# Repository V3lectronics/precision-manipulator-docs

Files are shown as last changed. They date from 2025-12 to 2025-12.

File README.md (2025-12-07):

# Precision Manipulator Docs
This is a university project about designing a precision XY manipulator that works only by mechanical means (no electricity). I have calculated the construction and designed this by myself using Autodesk Inventor.

# Images



rys-msl



# Use cases
- microscope tables
- assembly of small devices/systems e.g. robots
- any application requiring precise linear motion in 1 or 2 axis

# Technical drawings
.dwg and .pdf files can be downloaded from this repository.

# License
CERN Open Hardware Licence Version 2 - Strongly Reciprocal

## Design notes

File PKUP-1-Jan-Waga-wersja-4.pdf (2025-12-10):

P O L I T E C H N I K A W A R S Z A W S K A

PODSTAWY KONSTRUKCJI URZĄDZEŃ PRECYZYJNYCH

# Projekt 1

Temat nr MSL-25

# Moduł stolika liniowego

# Założenia konstrukcyjne

Wykonał: Jan Waga gr. MT-132 (B) Prowadzący: dr inż. Zbigniew Kusznierewicz

Warszawa 2025/2026

# Spis treści

Założenia konstrukcyjne | 1
Spis treści | 2
1. Wprowadzenie | 3
2. Wymagania techniczne | 3
3. Obliczenia konstrukcyjne | 4
Maksymalna długość separatora i prowadnic | 4
Liczba oraz średnica kulek | 4
Rzeczywista długość separatora | 5
Analiza obciążeń elementów tocznych prowadnicy | 5
Nacisk na elementy toczne | 5
Tarcie T1 | 5
Opory ruchu Tz całej prowadnicy | 5
Obciążenie siłą Fn2 działającą w płaszczyźnie ruchu i prostopadłą do kierunku ruchu
stolika | 6
Tarcie T2 | 6
Opory ruchu Ty całej prowadnicy | 6
Napięcie wstępne w prowadnicy | 6
Składowa Fnw normalna do płaszczyzny | 6
Tarcie T3 | 7
obl- obliczeniowy współczynnik tarcia | 7
Całkowite opory ruchu spowodowane napięciem wstępnym | 7
Całkowita siła oporów ruchu w prowadnicy | 7
Maksymalna siła działająca na rząd kulek po jednej stronie prowadnicy | 7
Maksymalna siła docisku pojedynczej kulki do płaszczyzny prowadnicy | 7
Naciski powierzchniowe Hertza | 8
Dobór materiałów | 8
Minimalna siła potrzebna do przesuwu stolika | 9
Wymagania sprężyny kasującej luz w połączeniu stolik-napęd | 9
Siła początkowa sprężyny | 9
Siła końcowa sprężyny | 9
Robocza strzałka ugięcia | 9
Siła miminalna | 10
Obciążenie graniczne (Pg) | 10
Założenie napięcia własnego ( P0) | 10
Ugięcie końcowe (fk) | 10
Wydłużenie odpowiadające napięciu własnemu (f0) | 10
Całkowite wydłużenie (f) | 10
Przyjęcie wartości wskaźnika średnicowego (w) | 10
Współczynnik poprawkowy (k) | 11
Dopuszczalne naprężenia styczne (k) | 11
Średnica drutu (d) | 11
Średnia średnica sprężyny (D) | 11

Liczba zwojów czynnych (zc) | 11
Wyznaczenie długości (l0w) części walcowej sprężyny nieobciążonej | 11
Przyjęcie kształtu zakończeń sprężyny i wynikającej stąd długości obu zaczepów (Z) 12
Wyznaczenie długości (l0) sprężyny nieobciążonej | 12
Wyznaczenie długości (lk) sprężyny na końcu skoku roboczego | 12
Wyznaczenie długości (lp) sprężyny na początku skoku roboczego | 12
Materiał na sprężynę | 12
Naciski powierzchniowe GM – stopka | 12
Wymiary GM Mitutoyo 150-804 | 13
Literatura | 14

# 1.Wprowadzenie

Przedmiotem projektu jest moduł stolika liniowego z napędem ręcznym, służący do przemieszczania niewielkich elementów z wysoką dokładnością wzdłuż jednej osi. Łączenie modułów w pary lub trójki pozwala uzyskać ruch w 2 lub 3 osiach (X,Y, Z).

# 2.Wymagania techniczne

- Ruch liniowy (L) do 25 mm,
- wymiary ruchomego blatu (axb): 100 x 75 mm,
- możliwość mocowania elementów do powierzchni roboczej (blatu),
- przewidywane obciążenia:

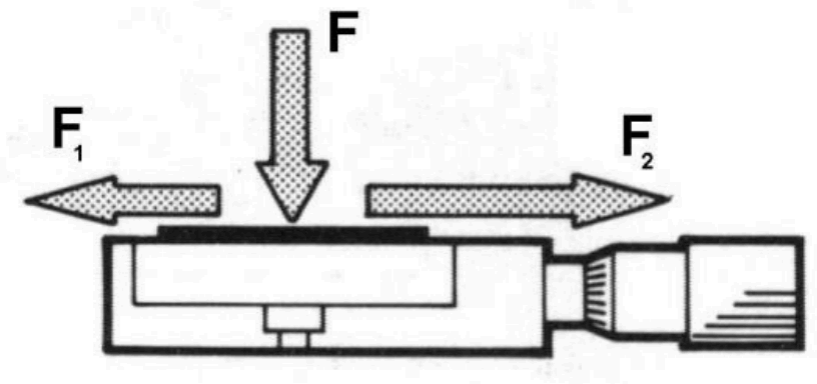
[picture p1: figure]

F

1 = 10N, F = 10, F

2 = 10N

- możliwość mocowania MSL do podłoża a także połączenia dwóch jednakowych modułów, w celu zbudowania manipulatora XY,
- zastosować pryzmatyczną prowadnicę liniową,
- zastosować gotową głowicę mikrometryczną GM, dobraną z katalogu,
- zapewnić bezluzowe sprzęgnięcie zespołu napędowego (GM) i karetki w każdym przypadku obciążenia przez docisk obu zespołów siłą wystarczającą do poprawnego działania modułu,
- dostosować projekt do przewidywanej wielkości produkcji od 50 do 500 sztuk rocznie,
- spełnić wymagania oczywiste: odporność na niewłaściwe użytkowanie, mały koszt, niewielkie wymiary i niewielki ciężar a także wygoda i bezpieczeństwo obsługi oraz napraw.
- dostosować mechanizm do pracy w pomieszczeniu w zakresie temperatur od +20°C do +30°C, przy niewielkim zapyleniu środowiska, itp.

# 3.Obliczenia konstrukcyjne

## Maksymalna długość separatora i prowadnic

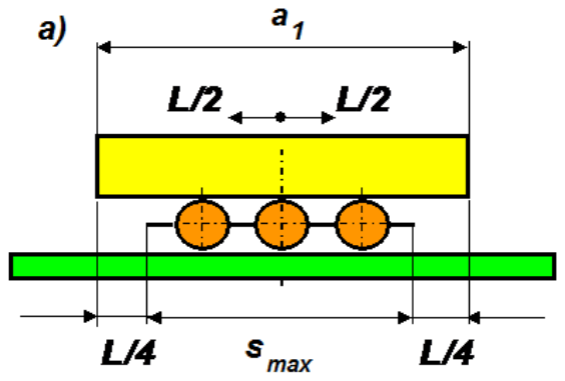
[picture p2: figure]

s | mm max = a − 0. 5L = 100 − 0. 5 · 25 = 87, 5

gdzie:
s – maksymalna długość separatora w mm max L – zakres ruchu stolika w mm
a – długość karetki w mm

## Liczba oraz średnica kulek

n

k = (s − 2)/(d

k + 2) = (87. 5 − 2)/(4 + 2) ≈ 14

gdzie:
d średnica kulki w mm k −
s − długość separatora w mm

Przyjęto 14 kulek o średnicach 4 mm.

Poniżej wyniki obliczeń dla pozostałych średnic:

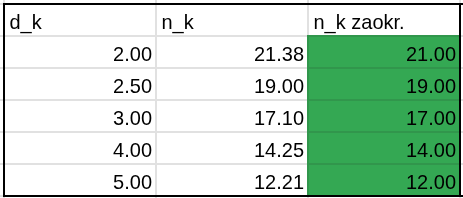
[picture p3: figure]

## Rzeczywista długość separatora

s = (n | mm k − 1)(d
k + 2) + 2(0, 5d

k + 2) = (14 − 1)(4 + 2) + 2(0, 5 · 4 + 2) = 86

gdzie:
n liczba kulek
k −
d średnica kulek mm k −

# Analiza obciążeń elementów tocznych prowadnicy

## Nacisk na elementy toczne

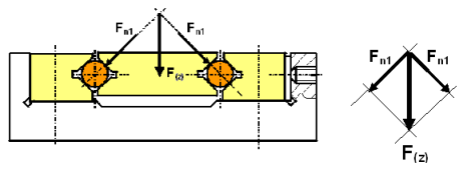
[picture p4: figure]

F | N n1 =

1
2

F 2 =

1
2

60 2 = 42, 43
Gdzie:
F siła naciskająca na elementy toczne w N n1 − F − wymagane obciążenie w N

## Tarcie T

1

T | N
1 = µ
obl

F

n1 = 0, 03 · 42, 43 = 1, 27 Gdzie:
µ obliczeniowy współczynnik tarcia
obl −

## Opory ruchu T całej prowadnicy

z

T | N z = 2T
1 = 2 · 1, 27 = 2, 55

## Obciążenie siłą F działającą w płaszczyźnie ruchu i

n2

## prostopadłą do kierunku ruchu stolika

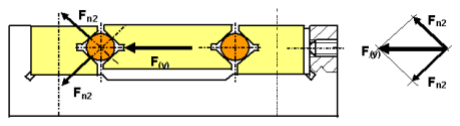
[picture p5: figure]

F | N n2 =

1
2

F 2 =

1
2

60 2 = 42, 43

## Tarcie T

2

T | N
2 = µ
obl

F

n2 = 0, 03 · 42, 43 = 1, 27 Gdzie:
µ obliczeniowy współczynnik tarcia
obl −

## Opory ruchu T całej prowadnicy

y

T | N
y = 2T

2 = 2 · 1, 27 = 2, 55

## Napięcie wstępne w prowadnicy

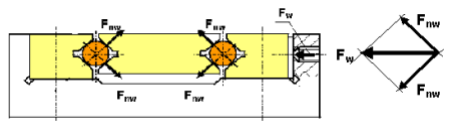
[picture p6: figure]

F | N w = kF = 0, 5 · 30 = 15
Gdzie:
k − współczynnik (0, 4 − 0, 5)

## Składowa F normalna do płaszczyzny

nw

F | N nw =

F
w

2
2 =

30· 2
2 = 21, 21
Gdzie:
F napięcie wstępne w N w −

## Tarcie T

3

T | N
3 = µ
obl

F

nw = 0, 03 · 21, 21 = 0, 64

Gdzie:

µ obliczeniowy współczynnik tarcia
obl −

## Całkowite opory ruchu spowodowane napięciem wstępnym

T | N w = 4T
3 = 4 · 0, 64

## Całkowita siła oporów ruchu w prowadnicy

T | N c = T
(z,y) + T

w = 2, 55 + 2, 55 = 5, 09
Gdzie:
T | obciążenie siłą | lub siłą | w N (z,y) − | F
z

F
y

## Maksymalna siła działająca na rząd kulek po jednej stronie prowadnicy

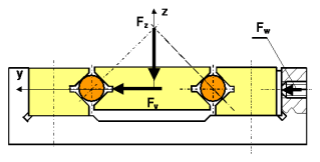
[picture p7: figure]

F | N
Σmax = F

n1 + F

nw = 42, 43 + 21, 21 = 63, 64

## Maksymalna siła docisku pojedynczej kulki do płaszczyzny prowadnicy

F | N
jmax =

F
Σmax
n | =
| 63,64
| 14,25 = 4, 47

## Naciski powierzchniowe Hertza

p

Hmax = 0, 578 ·

3 | F
jmax
r

2
[(1−v

2
1

)/E

1+(1−v

2
2

)/E
2

]

2 =

= 0, 578 · | MPa
3 | 4,47
2

2
[(1−0,3

2
)/210 000+(1−0,3)/210 000]

2 = 1386, 74

gdzie:

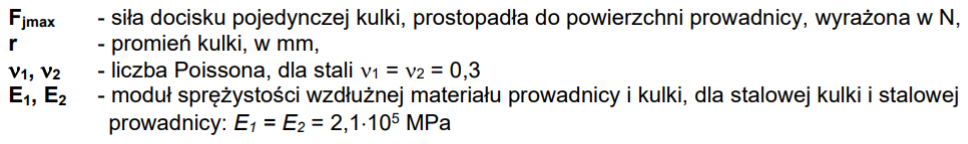
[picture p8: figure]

Wyniki obliczeń nacisków dla pozostałych średnic kulek:

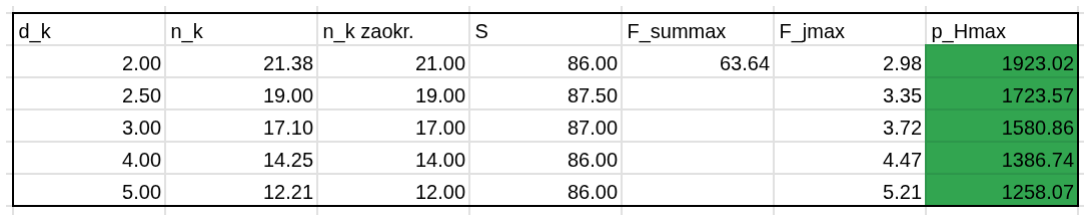
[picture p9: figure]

## Dobór materiałów

Po zastosowaniu kryterium wytrzymałościowego na prowadnicę wybrano stal niestopową C55 ulepszoną cieplnie do 52-55 HRC.

Na elementy toczne wybrano stal łożyskową 100Cr6.

## Minimalna siła potrzebna do przesuwu stolika

P | N min = (T
c + F
1

) = (5, 09 + 10) = 15, 09

gdzie:
T | suma oporów ruchu w N c −
F | obciążenie zgodne z wymaganiami w N
1 −

## Wymagania sprężyny kasującej luz w połączeniu stolik-napęd

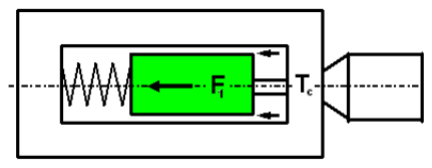
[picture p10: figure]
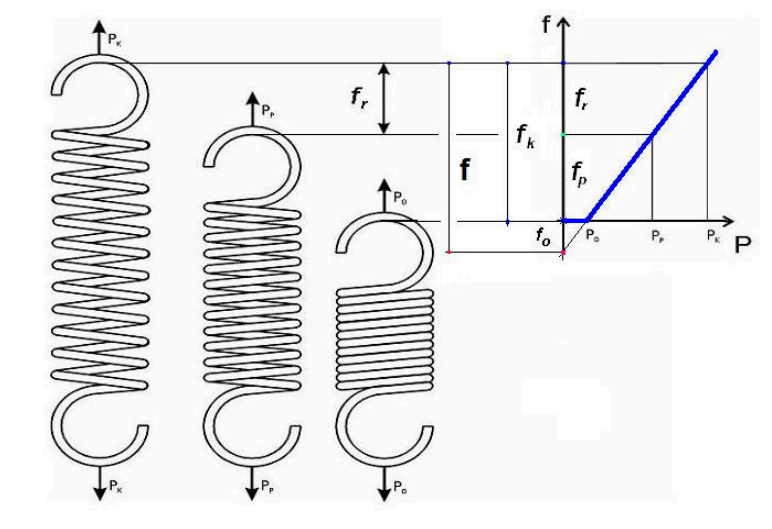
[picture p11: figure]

### Siła początkowa sprężyny

P | N
p = 1, 5 · P

min = 1, 5 · 15, 09 ≈ 22, 64

### Siła końcowa sprężyny

P | N k = 2 · P
p = 2 · 22, 64 = 45, 28

### Robocza strzałka ugięcia

f | mm r = L = 25

### Siła miminalna

P

min = F

1 + T
c
Gdzie:
F obciążenie zgodne w wymaganiami w N
1 −
T całkowity opór ruchu w N c −

### Obciążenie graniczne (P

g

)

P | N
g =

P
k
1− δ =

45,27
1−0,10 = 50, 30
Gdzie:
δ − współczynnik obciążenia granicznego

### Założenie napięcia własnego (P )

0
P

0 = (0, 25)(P
g

) = (0, 25)(50, 30) = 12, 58 N

### Ugięcie końcowe (f )

k

f | mm k = f
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
) = 25(

45,27−12,58
45,27−22,64

) = 36, 11

### Wydłużenie odpowiadające napięciu własnemu (f

0

)

f | mm
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
25·12,58
45,27−22,64 = 13, 89

### Całkowite wydłużenie (f)

f = f | mm k + f
0 = 36, 11 + 13, 89 = 50

### Przyjęcie wartości wskaźnika średnicowego (w)

w =

D
d = 8
(Przyjęto zgodnie z zaleceniem z przedziału 7-10)

### Współczynnik poprawkowy (k)

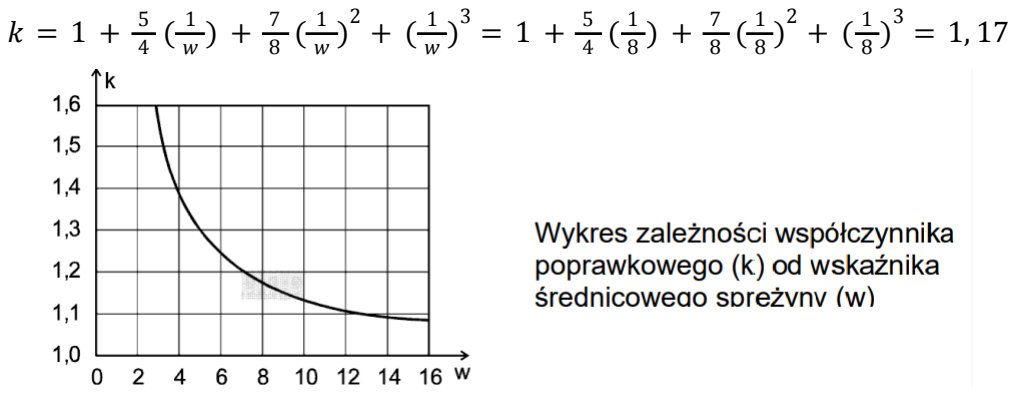
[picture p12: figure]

### Dopuszczalne naprężenia styczne (τ )

k
Przyjęto wartość τ | MPa zgodnie z zalecanym zakresem (600-1000 MPa).
k = 800

### Średnica drutu (d)

d' = | mm

8P

k wk
πτ
k

=

8·45,27·8·1,17
π·800 = 1, 16 ≈ 1, 20

Zaokrąglono w górę do znormalizowanej średnicy:

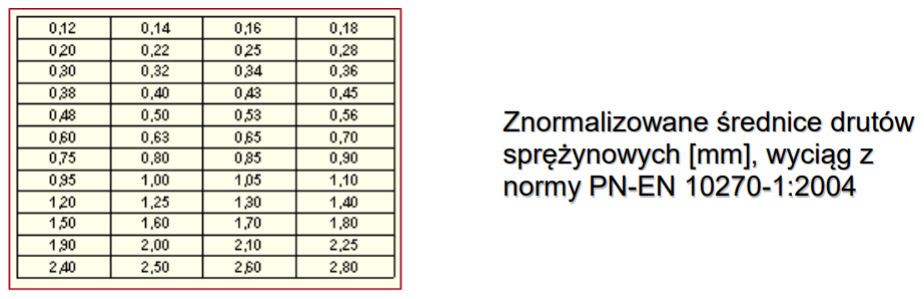
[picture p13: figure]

### Średnia średnica sprężyny (D)

D = wd = 8 · 4 = 32 mm

### Liczba zwojów czynnych (z )

c

z

c =

Gdf
8P

kw

3 =

8000 ·4·50
8·P
k

·8

3 ≈ 26

### Wyznaczenie długości (l ) części walcowej sprężyny nieobciążonej

0w
l | mm
0w = z
c

d = 1, 2 · 26 = 31, 20

### Przyjęcie kształtu zakończeń sprężyny i wynikającej stąd długości obu zaczepów (Z)

Z = D = 9, 6 mm

### Wyznaczenie długości (l ) sprężyny nieobciążonej

0
l | mm
0 = l | 0w + Z = 31, 20 + 9, 60 = 40, 8

### Wyznaczenie długości (l ) sprężyny na końcu skoku roboczego

k
l | mm k = l
0 − f | 0 + f = 40, 8 − 13, 89 + 50 = 76, 91

### Wyznaczenie długości (l ) sprężyny na początku skoku roboczego

p
l | mm
P = l

k − f

r = 76, 91 − 25 = 51, 91

## Materiał na sprężynę

Zgodnie z normą PN-EN 10270-2:2004, wybrano drut sprężynowy: PN EN 10270-2 – VDSiCr – 1,20.

# Naciski powierzchniowe GM – stopka

p

Hmax = 0, 578 ·

3 | P

k+F
2
r

2
[(1−v

2
1

)/E

1+(1−v

2
2

)/E
2

]

2 = 0, 578 ·

3 | 45,27+10
4

2
[(1−0,3

2
)/210 000+(1−0,17

2
)/420 000]

2 = 2471, 92

Gdzie:
P | siła końcowa sprężyny w N k −
F | obciążenie zgodne z wymaganiami w N
2 −
r − promień zakończenia GM
v liczba Poissona dla stali i węglika
1

, v

2 −
E moduł sprężystości wzdłużnej dla stali i węglika w MPa
1

, E

2 −

Zgodnie z zaleceniem prowadzącego nie uwzględniono ponownie tarcia we wzorze na F
k
gdyż zostało ono uwzględnione przy obliczeniach wymagań sprężyny.

Wartość p pozwala na skojarzenia węglika ze stalą łożyskową. Zatem wałeczek
Hmax
stykający się z głowicą jest wykonany ze stali łożyskowej, a sferyczne zakończenie głowicy jest wykonane z węglika.

Z katalogu Mitutoyo wybrano głowicę 150-804, ale można też użyć innej e.g. cyfrowej.

# Wymiary GM Mitutoyo 150-804

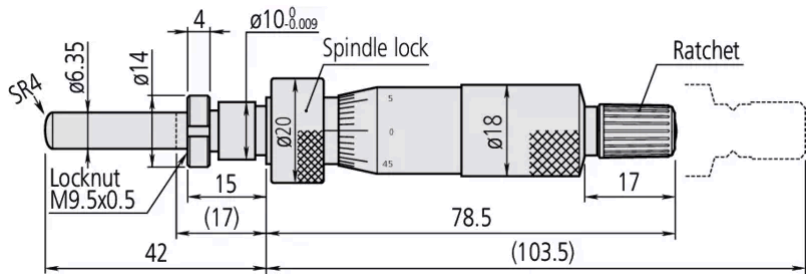
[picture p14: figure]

# Literatura

1. Oleksiuk W. red.: Konstrukcja przyrządów i urządzeń precyzyjnych. WNT, Warszawa 1996
2. PN-EN 10270-1:2011 - Drut stalowy na sprężyny mechaniczne -- Część 1: Drut sprężynowy ze stali niestopowej patentowany ciągniony na zimno
3. PN-EN 10270-2:2011 - Drut stalowy na sprężyny mechaniczne -- Część 2: Drut sprężynowy hartowany w oleju i odpuszczony
4. PN-EN 10270-3:2011 - Drut stalowy na sprężyny mechaniczne -- Część 3: Drut sprężynowy ze stali odpornej na korozję
5. Precyzyjna technika liniowa. Koszyki łożyskowe do prowadnic liniowych. Katalog Rollico 2007

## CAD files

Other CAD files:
rys-blat.dwg
rys-K-tor-kulek-blatu.dwg
podstawa.dwg
rys-msl.dwg
rys-sprezyna.dwg
rys-prowadnica.dwg
GM-150-804.ipt
K-tor-kulek-blatu.ipt
K-tor-kulek-blatu_MIR.ipt
K-tor-kulek.ipt
blat.ipt
kula_d4mm.ipt
kula_d4mm_MIR.ipt
msl.iam
nakretka-GM.ipt
oslonka.ipt
podstawa.ipt
separator-kul.ipt
separator-kul_MIR.ipt
spr-naciagowa.ipt
stopka.ipt
uchwyt-GM.ipt
wałek-blatu.ipt
wkladka gumowa.ipt

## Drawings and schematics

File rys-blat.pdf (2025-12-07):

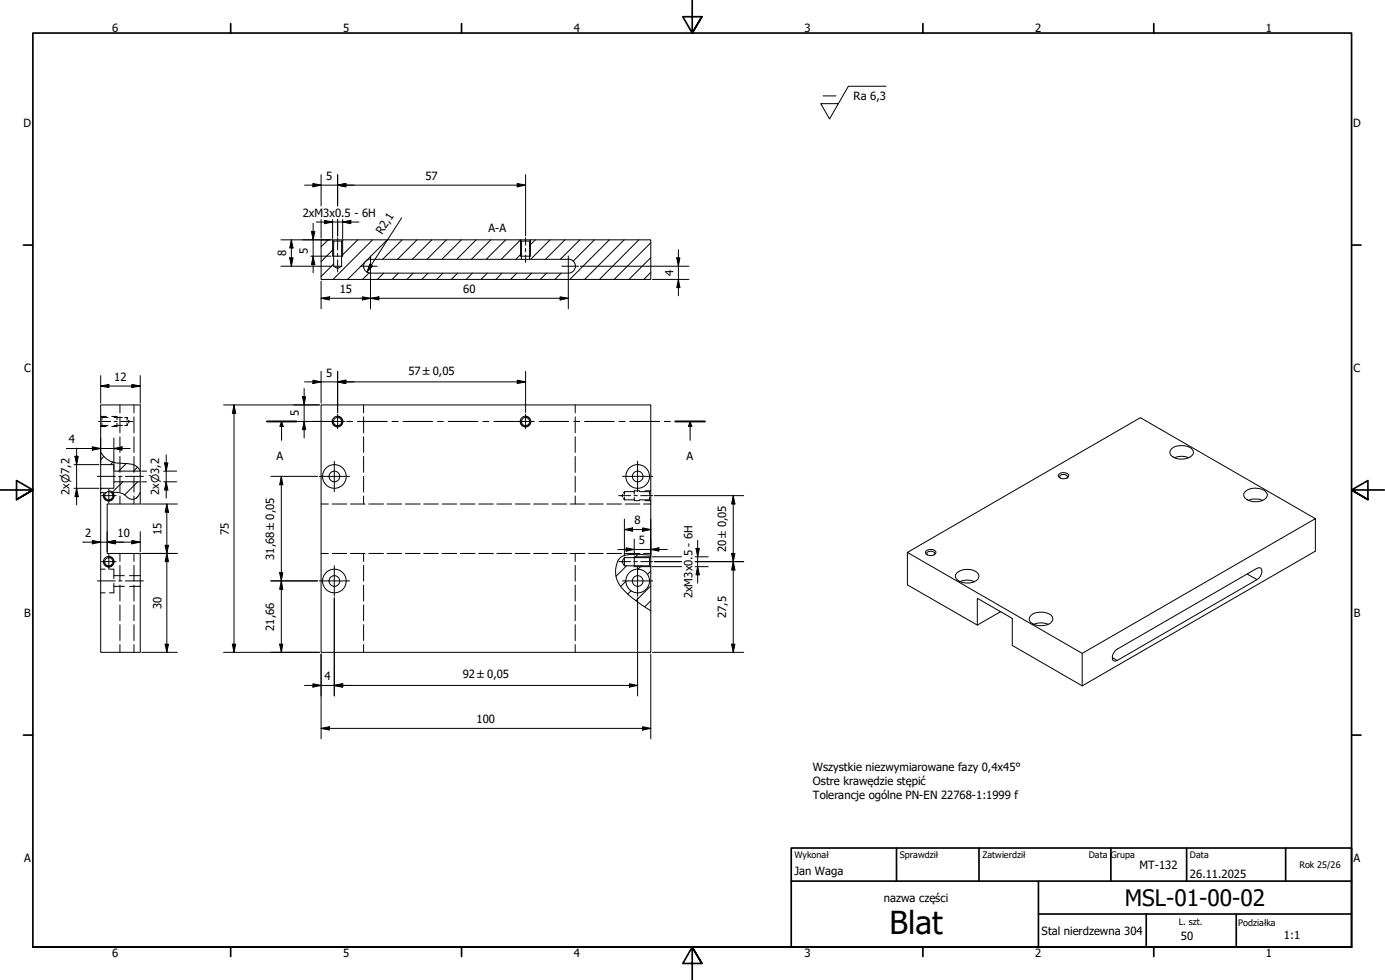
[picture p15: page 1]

Wszystkie niezwymiarowane fazy 0,4x45°
Ostre krawędzie stępić
Tolerancje ogólne PN-EN 22768-1:1999 f

Wykonał Jan Waga | Sprawdził | Zatwierdził Data | Grupa MT-132 | Data 26.11.2025 | Rok 25/26

nazwa części Blat | MSL-01-00-02

Stal nierdzewna 304 | L. szt. 50 | Podziałka 1:1

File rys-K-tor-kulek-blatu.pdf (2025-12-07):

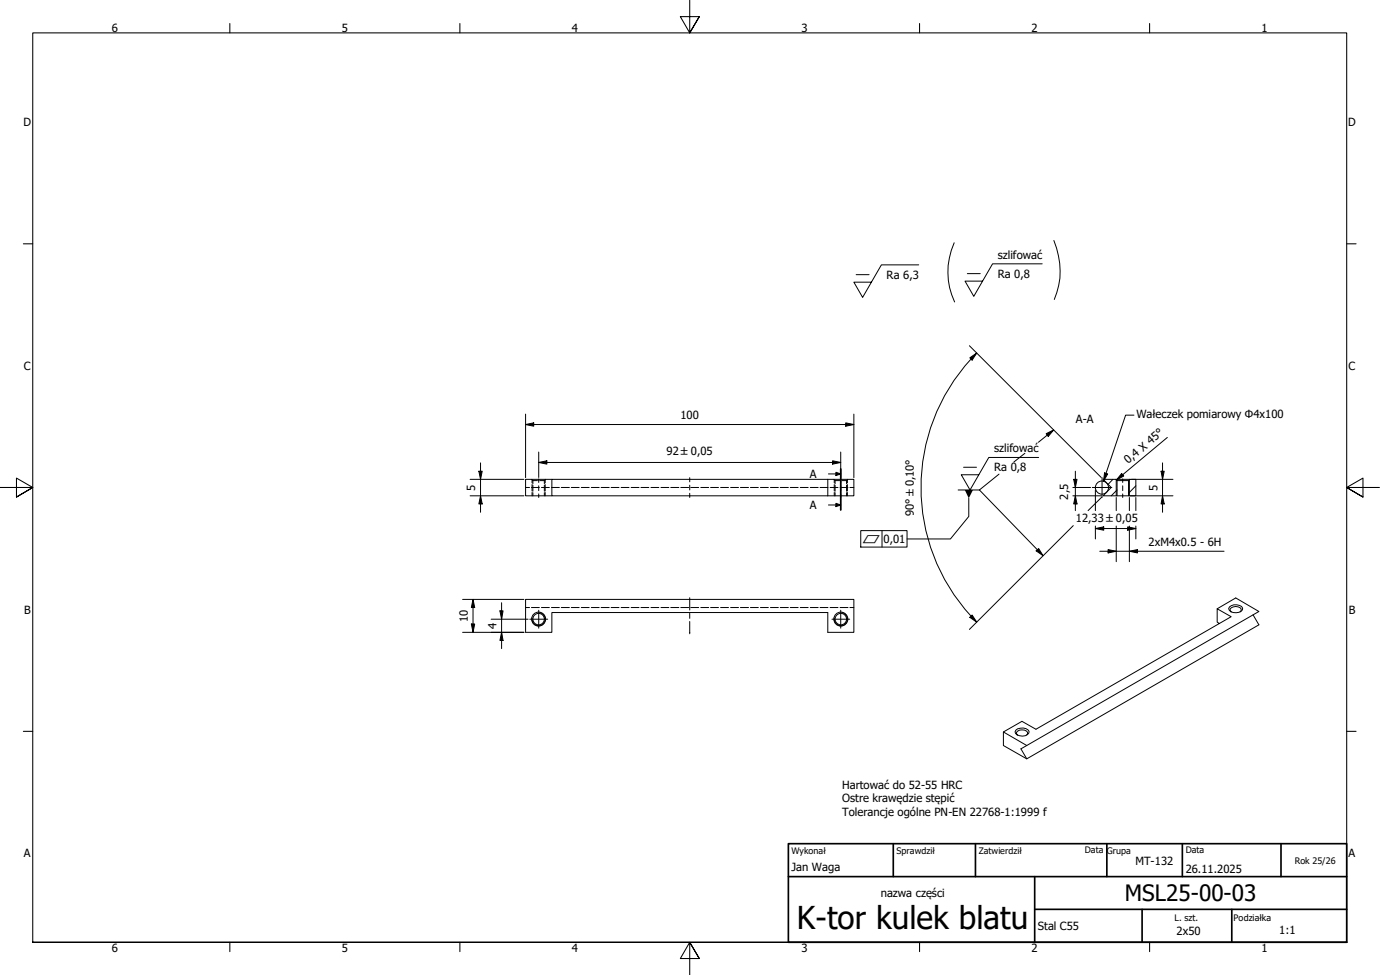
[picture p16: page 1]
Wałeczek pomiarowy Φ4x100

Hartować do 52-55 HRC
Ostre krawędzie stępić
Tolerancje ogólne PN-EN 22768-1:1999 f

Wykonał Jan Waga | Sprawdził | Zatwierdził Data | Grupa MT-132 | Data 26.11.2025 | Rok 25/26
nazwa części K-tor kulek blatu | MSL25-00-03

Stal C55 | L. szt. 2x50 | Podziałka 1:1

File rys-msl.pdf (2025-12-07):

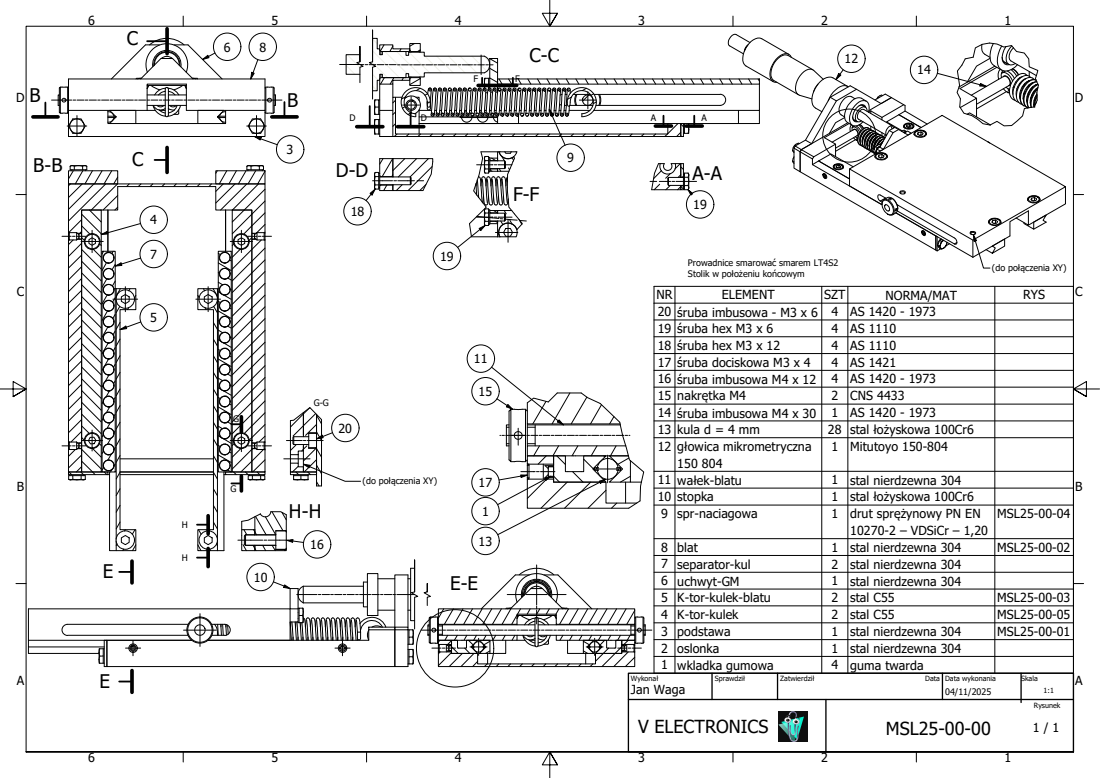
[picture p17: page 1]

N R | E L E M E N T | S Z T | N O R M A/ M A T | RY S
2 0 | ś r u b a i m b u s o w a -M 3 x 6 | 4 | A S 1 4 2 0 -1 9 7 3
1 9 | ś r u b a h e x M 3 x 6 | 4 | A S 1 1 1 0
1 8 | ś r u b a h e x M 3 x 1 2 | 4 | A S 1 1 1 0
1 7 | ś r u b a d o c i s k o w a M 3 x 4 | 4 | A S 1 4 2 1
1 6 | ś r u b a i m b u s o w a M 4 x 1 2 | 4 | A S 1 4 2 0 -1 9 7 3
1 5 | n a k r ę t k a M 4 | 2 | C N S 4 4 3 3
1 4 | ś r u b a i m b u s o w a M 4 x 3 0 | 1 | A S 1 4 2 0 -1 9 7 3
1 3 | k ula d = 4 m m | 2 8 | s t al ł o ż y s k o w a 1 0 0 C r 6
1 2 | g ł o w i c a m i k r o m e t r y c z n a 1 5 0 8 0 4 | 1 | M i t u t o y o 1 5 0 -8 0 4

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

8 | bla t | 1 | s t al n i e r d z e w n a 3 0 4 | M S L 2 5 -0 0 -0 2
7 | s e p a r a t o r -k ul | 2 | s t al n i e r d z e w n a 3 0 4
6 | u c h w y t -G M | 1 | s t al n i e r d z e w n a 3 0 4
5 | K -t o r -k ule k -bla t u | 2 | s t al C 5 5 | M S L 2 5 -0 0 -0 3
4 | K -t o r -k ule k | 2 | s t al C 5 5 | M S L 2 5 -0 0 -0 5
3 | p o d s t a w a | 1 | s t al n i e r d z e w n a 3 0 4 | M S L 2 5 -0 0 -0 1
2 | o slo n k a | 1 | s t al n i e r d z e w n a 3 0 4
1 | w kla d k a g u m o w a | 4 | g u m a t w a r d a
W y ko n a ł J a n W a g a | S p r a w d z i ł | Z a t w i e r d z i ł D a t a | D a t a w y ko n a n i a 0 4 / 1 1 / 2 0 2 5 | S kala 1 : 1
V E L E C T R O N I C S | Ry s u n e k M S L 2 5 -0 0 -0 0 1 / 1

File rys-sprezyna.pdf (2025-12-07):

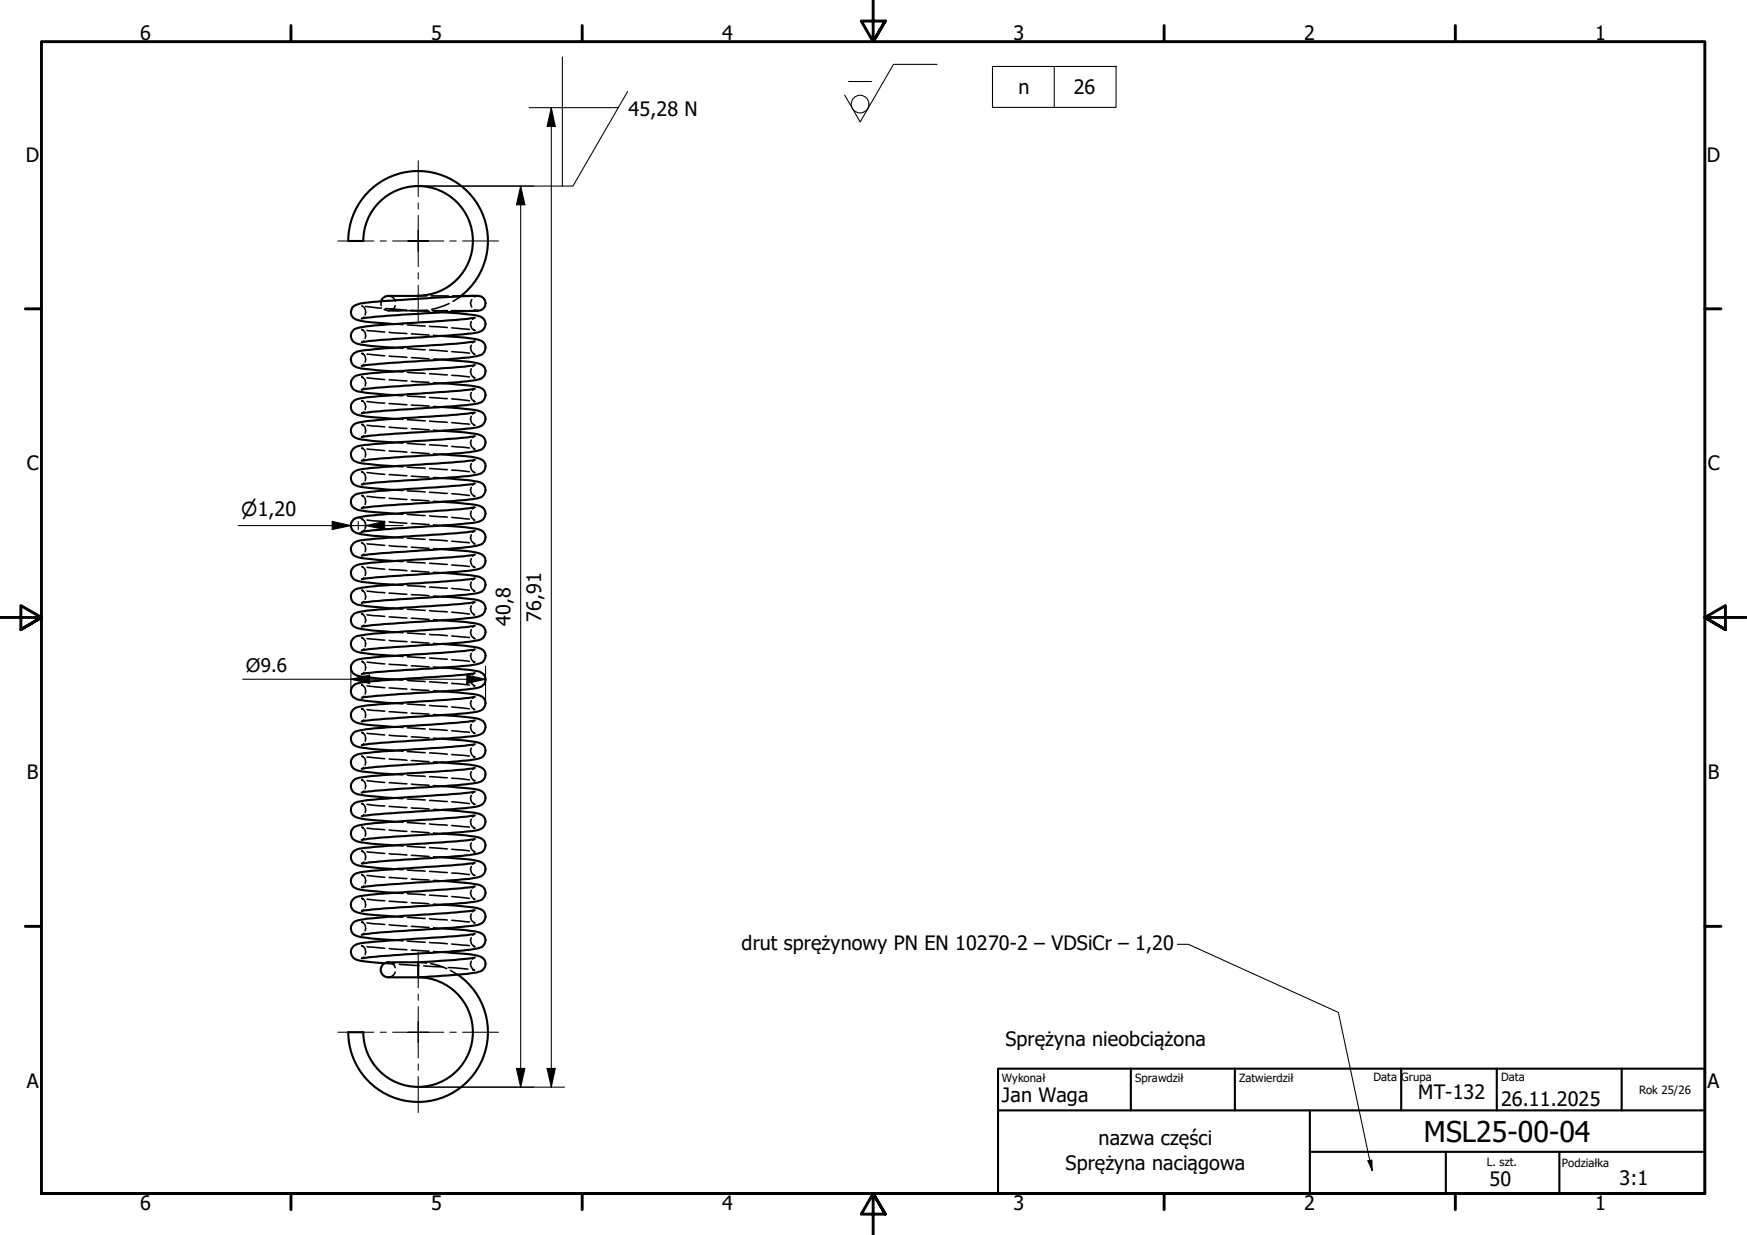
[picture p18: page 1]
Sprężyna nieobciążona

drut sprężynowy PN EN 10270-2 – VDSiCr – 1,20

Wykonał Jan Waga | Sprawdził | Zatwierdził Data | Grupa MT-132 | Data 26.11.2025 | Rok 25/26
nazwa części Sprężyna naciągowa | MSL25-00-04

L. szt. 50 | Podziałka 3:1
